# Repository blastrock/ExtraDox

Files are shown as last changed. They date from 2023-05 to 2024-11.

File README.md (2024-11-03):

# ExtraDox (v2)

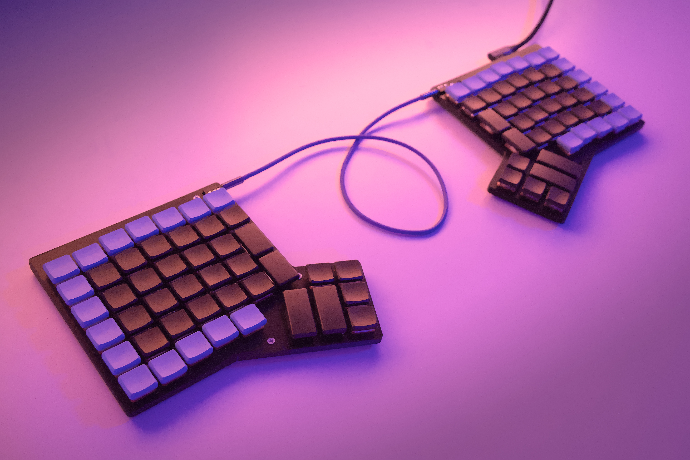
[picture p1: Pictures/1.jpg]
The ExtraDox


The ExtraDox is a split keyboard based off the ErgoDox. The main difference is
that it has an additional row of keys on the top. Also, it is a low-profile
keyboard designed for Choc v1 switches.

It features:

- An additional row of keys over the ErgoDox
- An USB-C port
- A single-board design (actually two boards), no extra controller board
- A TRRS connection between the two sides
- The 3 usual status LED
- The case is only 8mm thick, the keys are 18mm high from the desk

## What you need to build this keyboard

- The PCBs and their components (the MCU is soldered on the main board)
- The 3D-printed case
- 14x M2.5x8 screws and nuts
- 10x rubber pads to put under the keyboard to prevent slipping
- 90x Kailh Choc Hotswap sockets
- 90x Kailh Choc switches
- 82x 1u key caps
- 4x 1.5u key caps
- 4x 2u key caps
- 3x SMD status LED (see the Kicad project for details)
- 2x TRRS connector (see the Kicad project for details)
- 1x TRRS cable
- 1x USB-c cable

## About this keyboard

### PCB

The PCB is designed in Kicad. It is a SMD design and the project includes
component references from JLCPCB.

### Case

The case is designed to be 3D-printed. The case is screwed together with 7
M2.5x8 screws on each side, and their corresponding bolts.

### Firmware

[Here](https://github.com/blastrock/qmk_firmware/tree/extradox/keyboards/extradox) is a a fork of the QMK firmware with support for the ExtraDox.

## Known issues

Some capacitors are located right under an hotswap socket. It is still possible
to solder it, but the socket gets a little tilted.

## License



This work is licensed under a [Creative Commons Attribution-NonCommercial-ShareAlike 4.0 International License](http://creativecommons.org/licenses/by-nc-sa/4.0/).

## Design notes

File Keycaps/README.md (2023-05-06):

These keycaps are only used for renders, I never tried printing them.

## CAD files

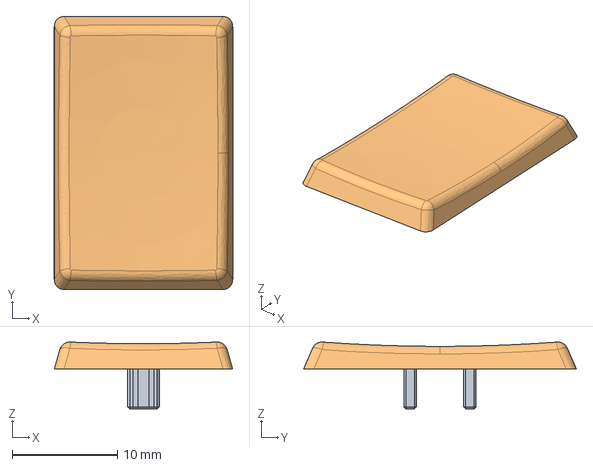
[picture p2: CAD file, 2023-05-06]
Keycaps/1.5u.step
17.0 x 26.0 x 6.38 mm

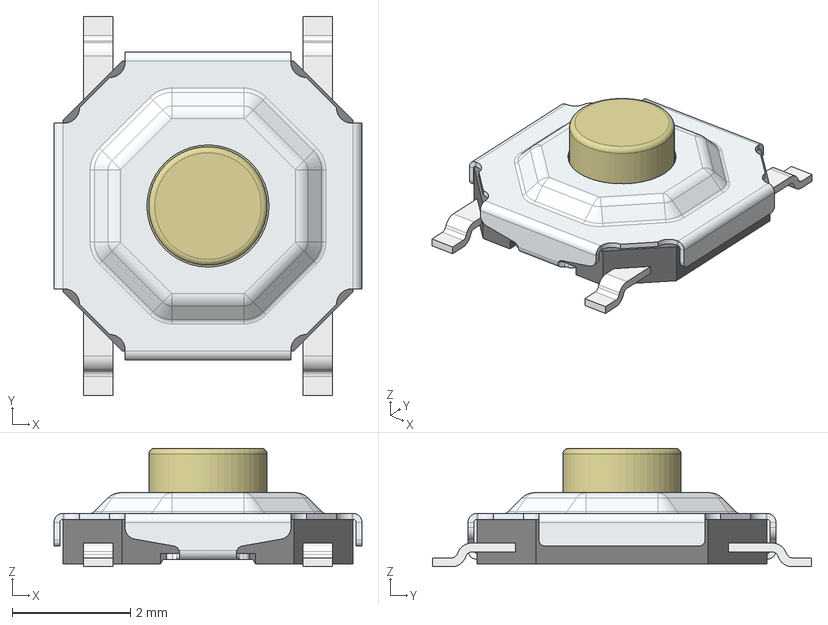
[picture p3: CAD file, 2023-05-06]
PCB/3dmodels/TS-1087S-020.stp
5.20 x 6.40 x 2.00 mm

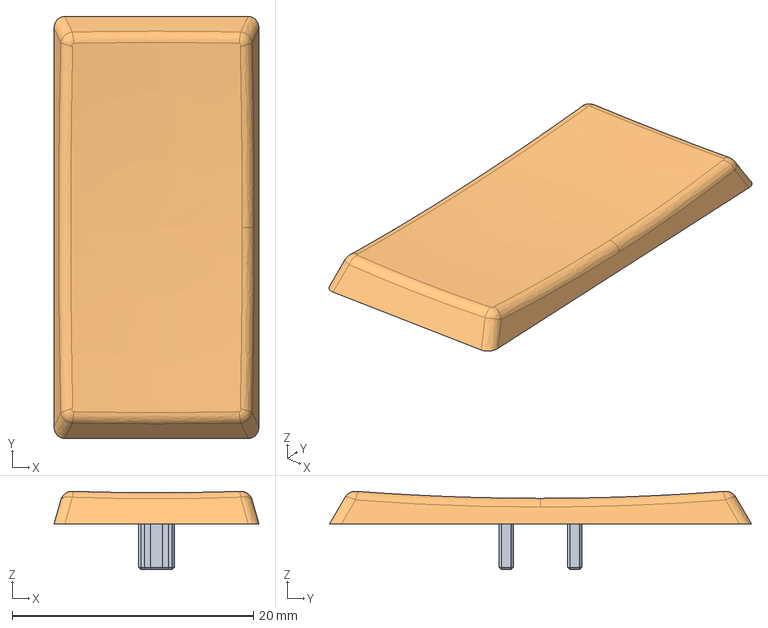
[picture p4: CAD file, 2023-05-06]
Keycaps/2u.step
17.0 x 35.0 x 6.50 mm

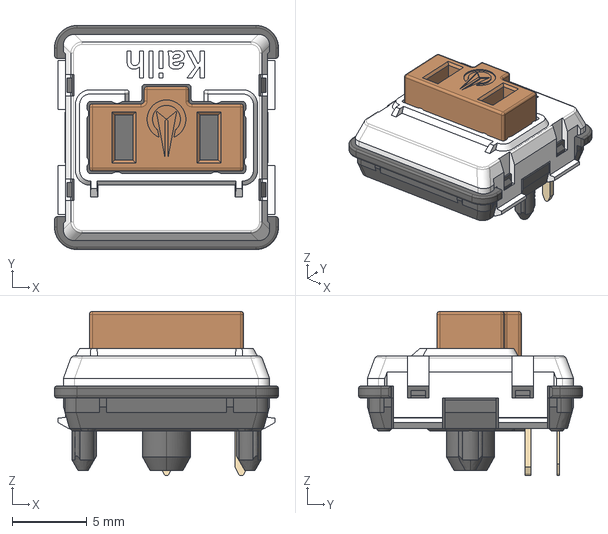
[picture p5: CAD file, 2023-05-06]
PCB/3dmodels/kailh_choc1.stp
15.0 x 15.0 x 11.0 mm

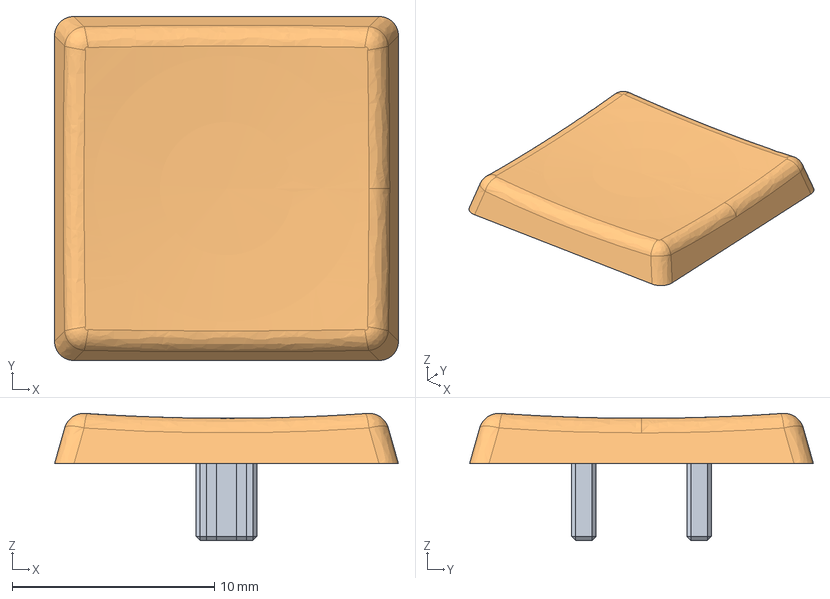
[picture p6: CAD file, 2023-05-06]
Keycaps/1u.step
17.0 x 17.0 x 6.29 mm

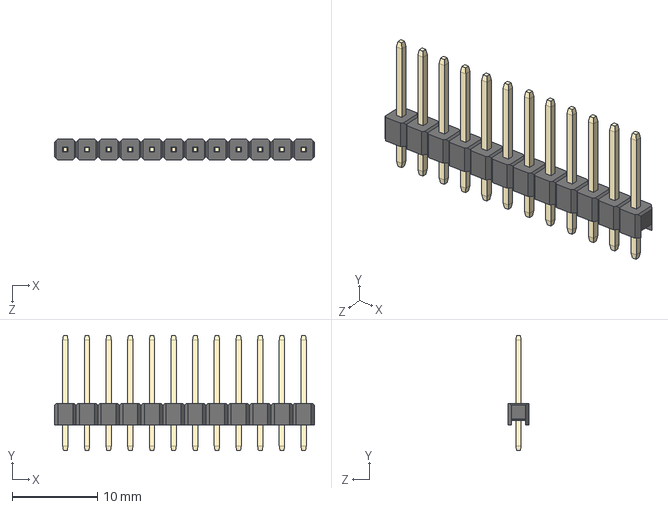
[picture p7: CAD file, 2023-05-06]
PCB/3dmodels/1x12 Male Pin Header.STEP
30.5 x 13.5 x 2.50 mm

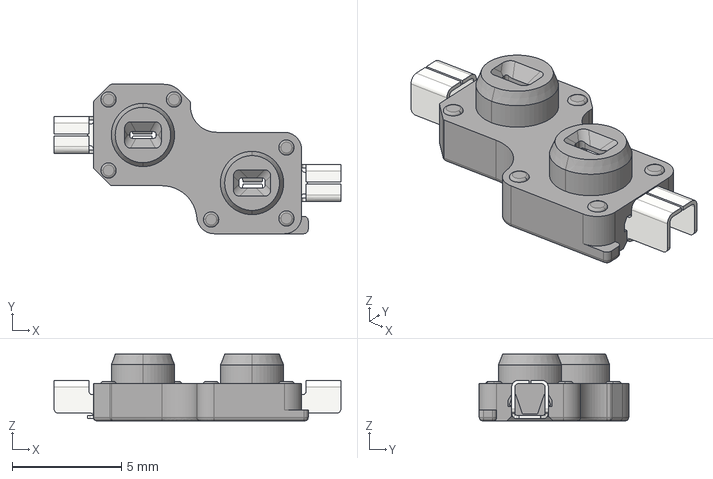
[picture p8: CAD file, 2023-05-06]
PCB/3dmodels/kailh_hotswap.stp
13.2 x 6.85 x 3.05 mm

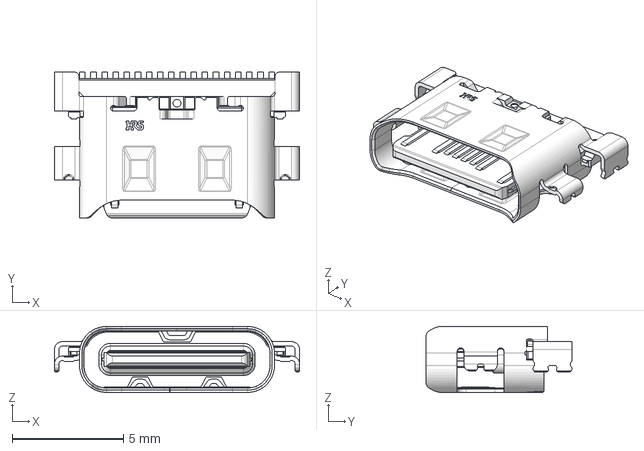
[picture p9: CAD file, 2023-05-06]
PCB/3dmodels/CX90M-16P.step
11.0 x 6.55 x 2.97 mm

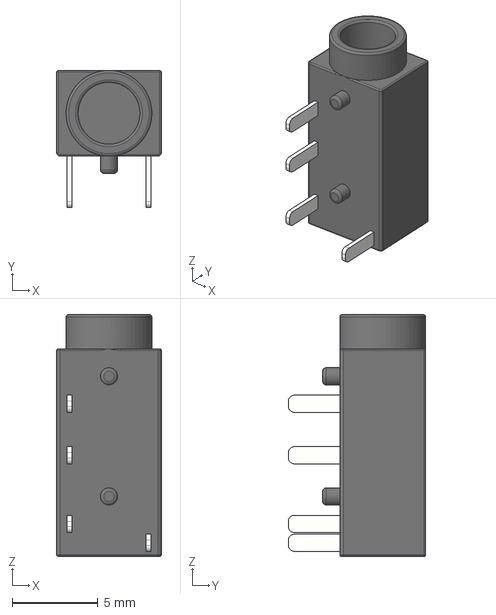
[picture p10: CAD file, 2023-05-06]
PCB/3dmodels/TRRS-PJ-320A.step
6.10 x 8.00 x 14.1 mm

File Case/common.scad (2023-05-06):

use <polyround.scad>
use <BOSL2/std.scad>
include <positions.scad>

boardThickness = 1.60;
caseRadius = 3;
bottomLayerThickness = 2;
boardHeight = bottomLayerThickness + 2;
topLayerThickness = 1.30;
topLayerOverBoard = boardThickness + 2.2-topLayerThickness;
topLayerHeight = topLayerOverBoard + boardHeight;
layerIntersectBottom = bottomLayerThickness + (topLayerHeight - bottomLayerThickness) / 2 - 0.5;
layerIntersectTop = bottomLayerThickness + (topLayerHeight - bottomLayerThickness) / 2 + 0.5;
screwHoleRadius = 3.2/2;
screwGuideBaseLargeRadius = 8/2;
screwGuideBaseRadius = 7/2;
screwGuideTopRadius = 5/2;
nutShortDiag = 5.4;
nutLongDiag = 2/sqrt(3) * nutShortDiag;

$fs = 0.5;

boardPoints = [
    [58, 64.5],
    [58, -62],
    [-11, -62],
    [-93, -100],
    [-118, -46],
    [-77, -27],
    [-77, 64.5],
];
outerShell = offset(boardPoints, delta=2, closed=true);
midShellIn = offset(boardPoints, delta=0.90, closed=true);
midShellOut = offset(boardPoints, delta=1.10, closed=true);

module base() {
  difference() {
    polyRoundExtrude([ for (p = outerShell) [ p.x, p.y, caseRadius ] ], layerIntersectTop, r1=0, r2=caseRadius);

    translate([0, 0, bottomLayerThickness])
      polyRoundExtrude([ for (p = boardPoints) [ p.x, p.y, caseRadius ] ], 10);
    translate([0, 0, layerIntersectBottom])
      difference() {
        translate([-150, -150, 0]) cube([300, 300, 10]);
        translate([0, 0, -5])
          polyRoundExtrude([ for (p = midShellOut) [ p.x, p.y, caseRadius ] ], 10, r1=0, r2=0);
      }
  }
}

module screwGuide() {
  color("green") cylinder(boardHeight, r1=screwGuideBaseLargeRadius, r2=screwGuideBaseRadius);
  //cylinder(topLayerHeight, r=screwGuideTopRadius);
}

module screwTopGuide() {
  cylinder(topLayerOverBoard-boardThickness+0.1, r=screwGuideTopRadius);
}

module screwCountersink() {
  h = 5;
  translate([0, 0, topLayerHeight-1])
    cylinder(h, r1=0, r2=h);
}

module screwHole() {
  translate([0, 0, -10])
    cylinder(r=screwHoleRadius, h=20);
}

module nutHole() {
  translate([0, 0, -1])
    cylinder(1+3, r=nutLongDiag/2, $fn=6);
}

module switchHole() {
  linear_extrude(100)
    square([14.3, 14], center=true);
}

module forHoles(holePositions) {
  for ( h = holePositions )
    translate([h.x, h.y])
      children();
}

module longHole(radius, width) {
  union() {
    translate([-width/2, 0])
    circle(radius);
    translate([+width/2, 0])
    circle(radius);
    square([width, radius*2], center=true);
  }
}

module usbcHole() {
  union() {
    linear_extrude(100)
      longHole(2, 6);
    translate([0, 0, 6])
      linear_extrude(100)
        longHole(3, 10);
  }
}

module jackHole() {
  union() {
    // linear_extrude(100)
    //   circle(d=6);
    translate([0, 0, -3])
      //cube([6, 6.5, 13], center=true);
      cube([10, 6.5, 20], center=true);
  }
}

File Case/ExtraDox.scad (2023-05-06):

use <rightBottom.scad>
use <rightTop.scad>
use <leftBottom.scad>
use <leftTop.scad>
include <common.scad>

part_rightBottomCase();
part_rightTopCase();

%translate([0, 0, boardHeight])
  import("ExtraDox-Right.stl");

translate([-250, 0, 0]) {
  part_leftBottomCase();
  part_leftTopCase();

  %translate([0, 0, boardHeight])
    import("ExtraDox-Left.stl");
}

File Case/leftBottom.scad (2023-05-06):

include <common.scad>

module part_leftBottomCase() {
  difference() {
    union() {
      mirror([1, 0, 0])
        base();
      forHoles(leftHolePositions)
        screwGuide();
    }
    forHoles(leftHolePositions) {
      screwHole();
      nutHole();
    }
  }
}

part_leftBottomCase();

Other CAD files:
Case/ExtraDox-Right.step
Case/ExtraDox-Left.step
PCB/3dmodels/choc2u.step
PCB/3dmodels/choc1_5u.step
PCB/3dmodels/Kailh Choc FunkMonk 1u.step
Case/leftTop.scad
Case/polyround.scad
Case/positions.scad
Case/rightBottom.scad
Case/rightTop.scad
Keycaps/1u.FCStd

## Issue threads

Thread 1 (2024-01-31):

Boards

Yenots83, 2024-01-31:
Hi!

Was wondering if you still had any boards for sale?

Think this is the only way to get in touch :)

blastrock, 2024-02-01:
Hello!

Unfortunately, I shipped my last boards a couple weeks ago, I don't have any more to sell.

Closed 2024-02-01.

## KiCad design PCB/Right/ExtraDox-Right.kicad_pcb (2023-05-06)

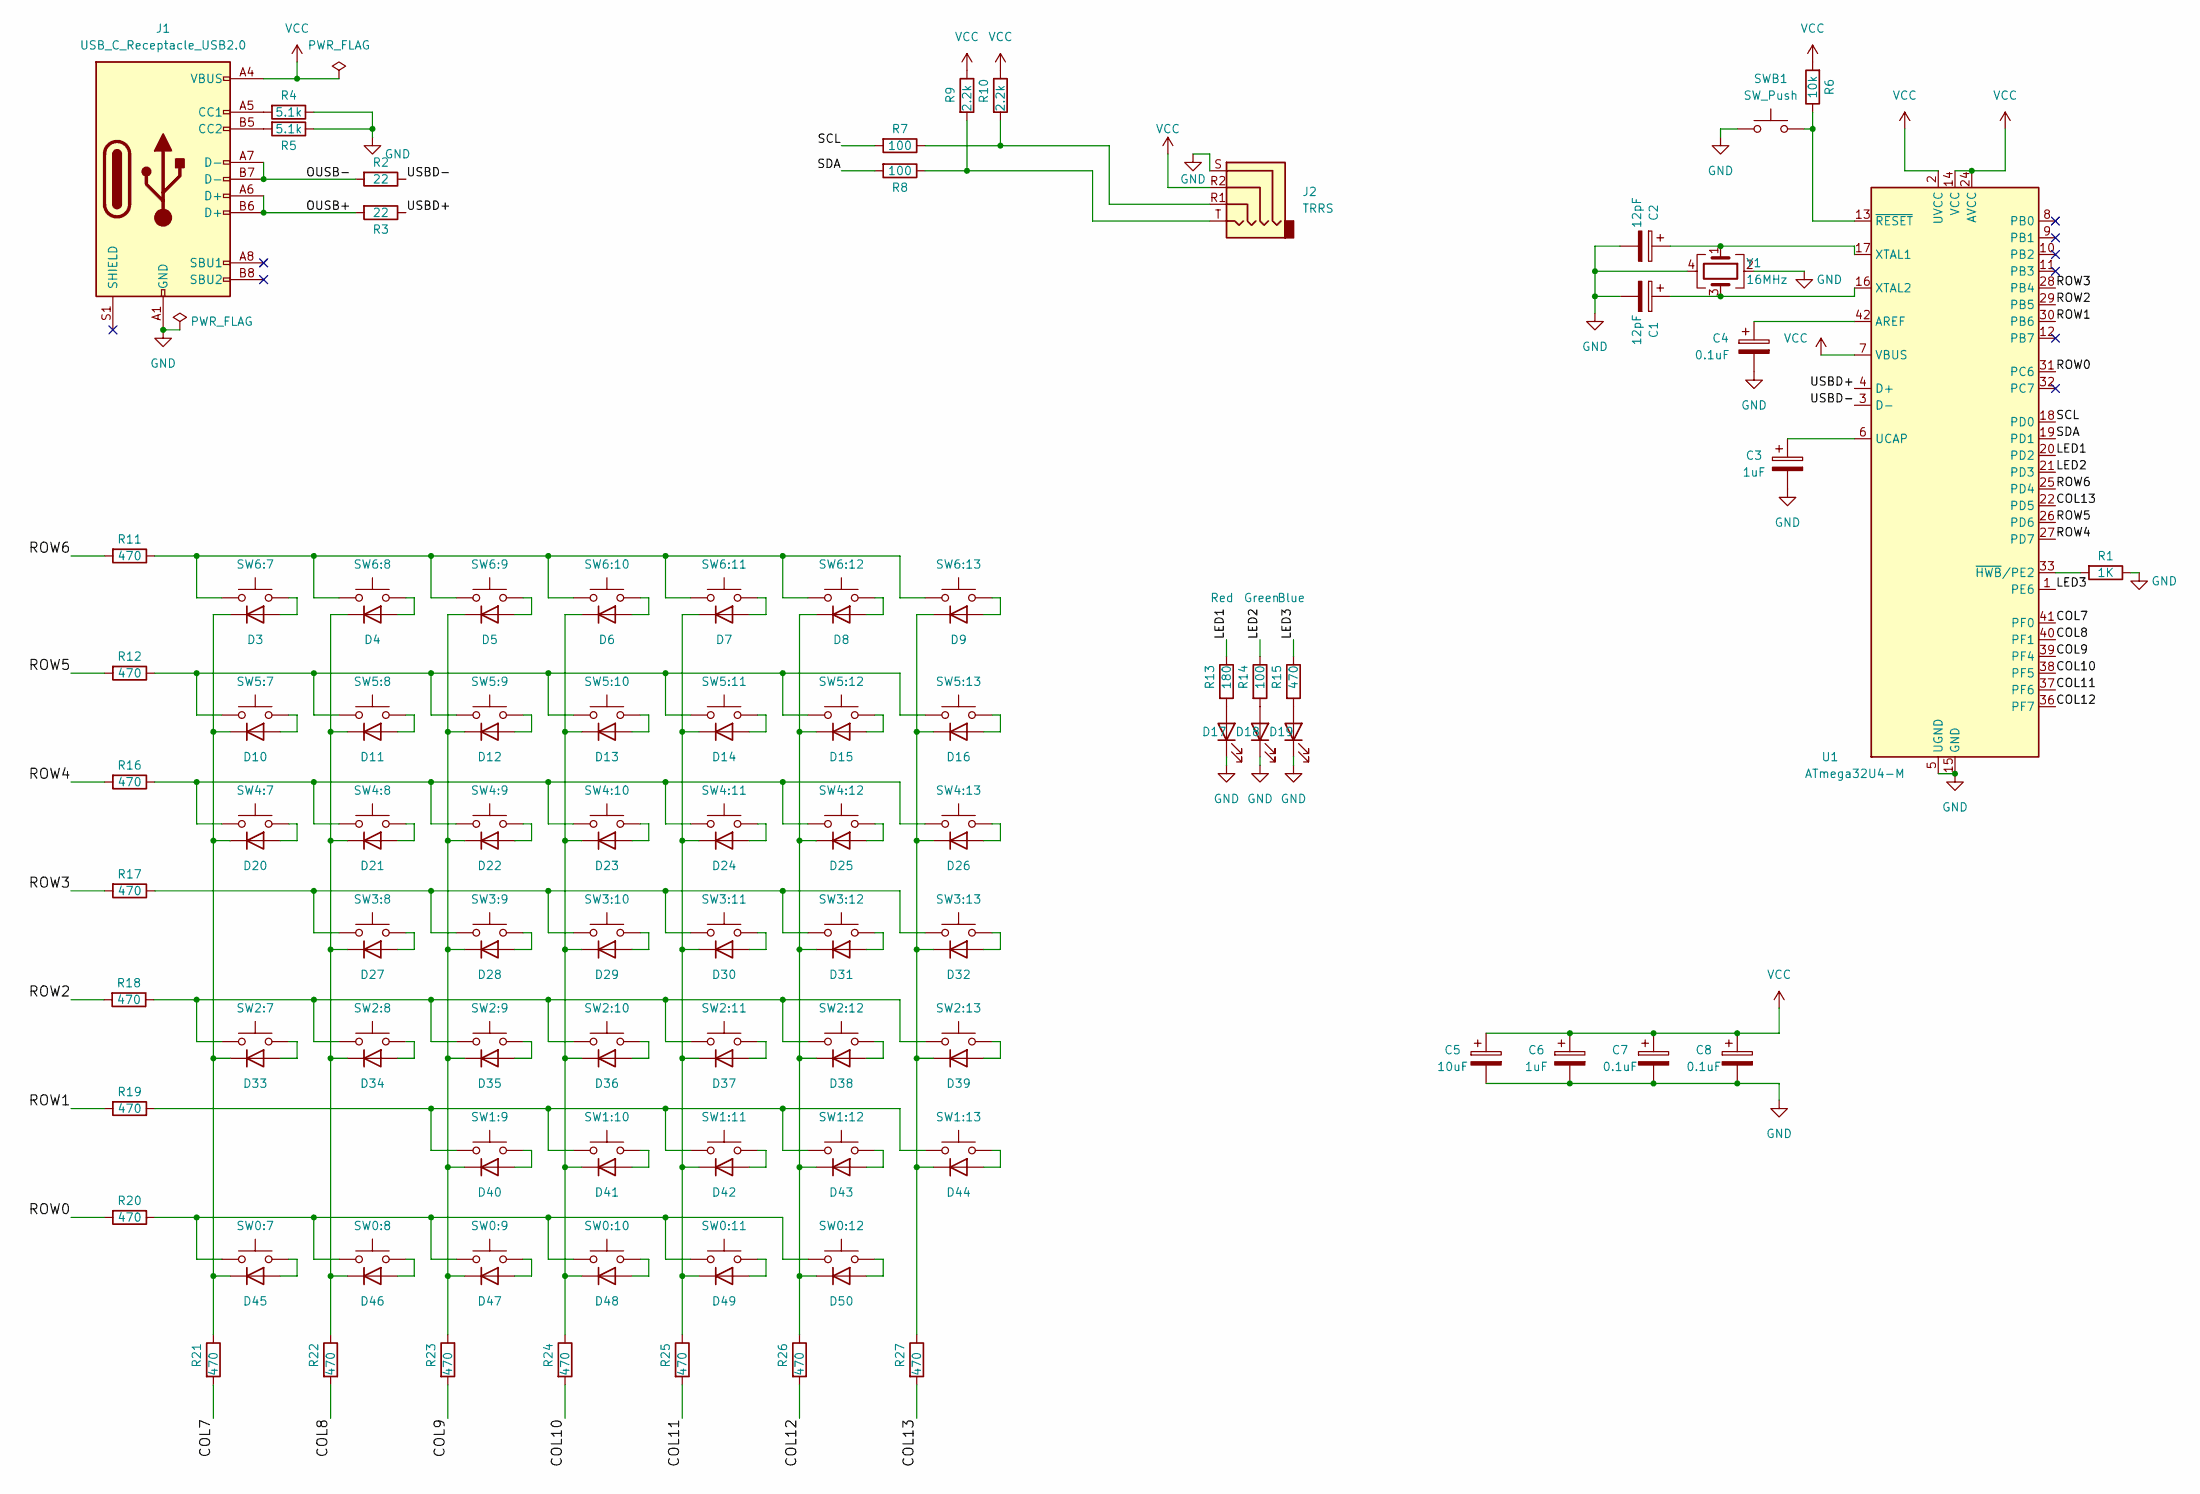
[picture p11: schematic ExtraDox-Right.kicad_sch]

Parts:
C1, C2: 12pF; C_0402_1005Metric; LCSC C1547
C3, C6: 1uF; C_0402_1005Metric; LCSC C52923
C4, C7, C8: 0.1uF; C_0402_1005Metric; LCSC C307331
C5: 10uF; C_0402_1005Metric; LCSC C15525
D3, D4, D5, D6, D7, D8, D9, D10, D11, D12, D13, D14, D15, D16, D20, D21, D22, D23, D24, D25, D26, D27, D28, D29, D30, D31, D32, D33, D34, D35, D36, D37, D38, D39, D40, D41, D42, D43, D44, D45, D46, D47, D48, D49, D50: D; D_SOD-123F; LCSC C64898
D17: Red; D_0603_1608Metric; LCSC C2286
D18: Green; D_0603_1608Metric; LCSC C72043
D19: Blue; D_0603_1608Metric; LCSC C72041
J1: USB_C_Receptacle_USB2.0; HRS_CX90M-16P; LCSC C2889324
J2: TRRS; TRRS-PJ-320A
R1: 1K; R_0402_1005Metric; LCSC C11702
R2, R3: 22; R_0402_1005Metric; LCSC C25092
R4, R5: 5.1k; R_0402_1005Metric; LCSC C25905
R6: 10k; R_0402_1005Metric; LCSC C25744
R7, R8, R14: 100; R_0402_1005Metric; LCSC C25076
R9, R10: 2.2k; R_0402_1005Metric; LCSC C25879
R11, R12, R15, R16, R17, R18, R19, R20, R21, R22, R23, R24, R25, R26, R27: 470; R_0402_1005Metric; LCSC C25117
R13: 180; R_0402_1005Metric; LCSC C25082
SW0:7, SW0:8, SW0:9, SW0:12, SW1:9, SW1:10, SW1:11, SW1:12, SW1:13, SW2:8, SW2:9, SW2:10, SW2:11, SW2:12, SW2:13, SW3:8, SW3:9, SW3:10, SW3:11, SW3:12, SW3:13, SW4:8, SW4:9, SW4:10, SW4:11, SW4:12, SW4:13, SW5:7, SW5:8, SW5:9, SW5:10, SW5:11, SW5:12, SW5:13, SW6:7, SW6:8, SW6:9, SW6:10, SW6:11, SW6:12, SW6:13: SW_Push; KailhHotswapChoc1
SW0:10, SW0:11: SW_Push; KailhHotswapChoc2
SW2:7, SW4:7: SW_Push; KailhHotswapChoc15
SWB1: SW_Push; TS-1087S; LCSC C455263
U1: ATmega32U4-M; QFN-44-1EP_7x7mm_P0.5mm_EP5.2x5.2mm_ThermalVias_JLCPCB; LCSC C112161
Y1: 16MHz; Crystal_SMD_3225-4Pin_3.2x2.5mm; LCSC C13738

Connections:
/COL7: R21.2, U1.41 (PF0)
/COL8: R22.2, U1.40 (PF1)
/COL9: R23.2, U1.39 (PF4)
/COL10: R24.2, U1.38 (PF5)
/COL11: R25.2, U1.37 (PF6)
/COL12: R26.2, U1.36 (PF7)
/COL13: R27.2, U1.22 (PD5)
/LED1: R13.1, U1.20 (PD2)
/LED2: R14.1, U1.21 (PD3)
/LED3: R15.1, U1.1 (PE6)
/OUSB+: J1.A6 (D+), J1.B6 (D+), R3.2
/OUSB-: J1.A7 (D-), J1.B7 (D-), R2.2
/ROW0: R20.2, U1.31 (PC6)
/ROW1: R19.2, U1.30 (PB6)
/ROW2: R18.2, U1.29 (PB5)
/ROW3: R17.2, U1.28 (PB4)
/ROW4: R16.2, U1.27 (PD7)
/ROW5: R12.2, U1.26 (PD6)
/ROW6: R11.2, U1.25 (PD4)
/SCL: R7.2, U1.18 (PD0)
/SDA: R8.2, U1.19 (PD1)
/USBD+: R3.1, U1.4 (D+)
/USBD-: R2.1, U1.3 (D-)
GND: C1.2, C2.2, C3.2, C4.2, C5.2, C6.2, C7.2, C8.2, D17.1 (K), D18.1 (K), D19.1 (K), J1.A1 (GND), J1.A12 (GND), J1.B1 (GND), J1.B12 (GND), J2.S, R1.1, R4.1, R5.1, SWB1.1, U1.5 (UGND), U1.15 (GND), U1.23 (GND), U1.35 (GND), U1.43 (GND), U1.45 (GND), Y1.2, Y1.4
unnamed: C1.1, U1.16 (XTAL2), Y1.3
unnamed: C2.1, U1.17 (XTAL1), Y1.1
unnamed: C3.1, U1.6 (UCAP)
unnamed: C4.1, U1.42 (AREF)
unnamed: D3.2 (A), SW6:7.2
unnamed: D4.2 (A), SW6:8.2
unnamed: D5.2 (A), SW6:9.2
unnamed: D6.2 (A), SW6:10.2
unnamed: D7.2 (A), SW6:11.2
unnamed: D8.2 (A), SW6:12.2
unnamed: D9.2 (A), SW6:13.2
unnamed: D3.1 (K), D10.1 (K), D20.1 (K), D33.1 (K), D45.1 (K), R21.1
unnamed: D10.2 (A), SW5:7.2
unnamed: D4.1 (K), D11.1 (K), D21.1 (K), D27.1 (K), D34.1 (K), D46.1 (K), R22.1
unnamed: D11.2 (A), SW5:8.2
unnamed: D5.1 (K), D12.1 (K), D22.1 (K), D28.1 (K), D35.1 (K), D40.1 (K), D47.1 (K), R23.1
unnamed: D12.2 (A), SW5:9.2
unnamed: D6.1 (K), D13.1 (K), D23.1 (K), D29.1 (K), D36.1 (K), D41.1 (K), D48.1 (K), R24.1
unnamed: D13.2 (A), SW5:10.2
unnamed: D7.1 (K), D14.1 (K), D24.1 (K), D30.1 (K), D37.1 (K), D42.1 (K), D49.1 (K), R25.1
unnamed: D14.2 (A), SW5:11.2
unnamed: D8.1 (K), D15.1 (K), D25.1 (K), D31.1 (K), D38.1 (K), D43.1 (K), D50.1 (K), R26.1
unnamed: D15.2 (A), SW5:12.2
unnamed: D9.1 (K), D16.1 (K), D26.1 (K), D32.1 (K), D39.1 (K), D44.1 (K), R27.1
unnamed: D16.2 (A), SW5:13.2
unnamed: D17.2 (A), R13.2
unnamed: D18.2 (A), R14.2
unnamed: D19.2 (A), R15.2
unnamed: D20.2 (A), SW4:7.2
unnamed: D21.2 (A), SW4:8.2
unnamed: D22.2 (A), SW4:9.2
unnamed: D23.2 (A), SW4:10.2
unnamed: D24.2 (A), SW4:11.2
unnamed: D25.2 (A), SW4:12.2
unnamed: D26.2 (A), SW4:13.2
unnamed: D27.2 (A), SW3:8.2
unnamed: D28.2 (A), SW3:9.2
unnamed: D29.2 (A), SW3:10.2
unnamed: D30.2 (A), SW3:11.2
unnamed: D31.2 (A), SW3:12.2
unnamed: D32.2 (A), SW3:13.2
unnamed: D33.2 (A), SW2:7.2
unnamed: D34.2 (A), SW2:8.2
unnamed: D35.2 (A), SW2:9.2
unnamed: D36.2 (A), SW2:10.2
unnamed: D37.2 (A), SW2:11.2
unnamed: D38.2 (A), SW2:12.2
unnamed: D39.2 (A), SW2:13.2
unnamed: D40.2 (A), SW1:9.2
unnamed: D41.2 (A), SW1:10.2
unnamed: D42.2 (A), SW1:11.2
unnamed: D43.2 (A), SW1:12.2
unnamed: D44.2 (A), SW1:13.2
unnamed: D45.2 (A), SW0:7.2
unnamed: D46.2 (A), SW0:8.2
unnamed: D47.2 (A), SW0:9.2
unnamed: D48.2 (A), SW0:10.2
unnamed: D49.2 (A), SW0:11.2
unnamed: D50.2 (A), SW0:12.2
unnamed: J1.A5 (CC1), R4.2
unnamed: J1.B5 (CC2), R5.2
unnamed: J2.R1, R7.1, R10.2
unnamed: J2.T, R8.1, R9.2
unnamed: R1.2, U1.33 (~HWB/PE2)
unnamed: R6.1, SWB1.2, U1.13 (~RESET)
unnamed: R11.1, SW6:7.1, SW6:8.1, SW6:9.1, SW6:10.1, SW6:11.1, SW6:12.1, SW6:13.1
unnamed: R12.1, SW5:7.1, SW5:8.1, SW5:9.1, SW5:10.1, SW5:11.1, SW5:12.1, SW5:13.1
unnamed: R16.1, SW4:7.1, SW4:8.1, SW4:9.1, SW4:10.1, SW4:11.1, SW4:12.1, SW4:13.1
unnamed: R17.1, SW3:8.1, SW3:9.1, SW3:10.1, SW3:11.1, SW3:12.1, SW3:13.1
unnamed: R18.1, SW2:7.1, SW2:8.1, SW2:9.1, SW2:10.1, SW2:11.1, SW2:12.1, SW2:13.1
unnamed: R19.1, SW1:9.1, SW1:10.1, SW1:11.1, SW1:12.1, SW1:13.1
unnamed: R20.1, SW0:7.1, SW0:8.1, SW0:9.1, SW0:10.1, SW0:11.1, SW0:12.1
VCC: C5.1, C6.1, C7.1, C8.1, J1.A4 (VBUS), J1.A9 (VBUS), J1.B4 (VBUS), J1.B9 (VBUS), J2.R2, R6.2, R9.1, R10.1, U1.2 (UVCC), U1.7 (VBUS), U1.14 (VCC), U1.24 (AVCC), U1.34 (VCC), U1.44 (AVCC)

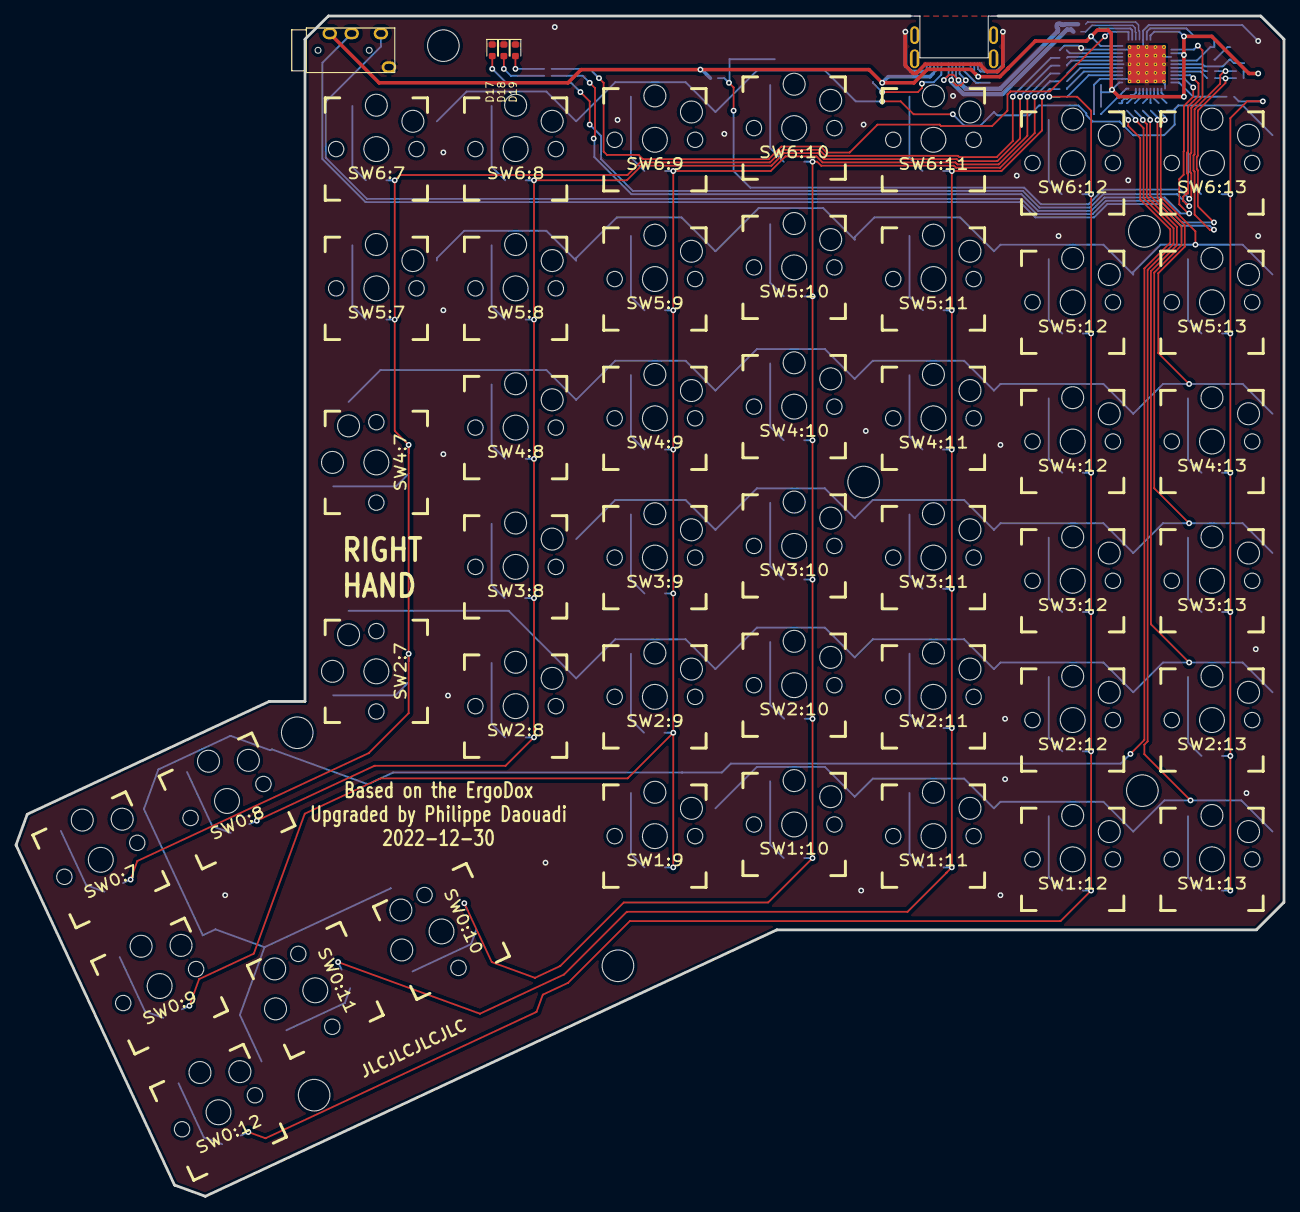
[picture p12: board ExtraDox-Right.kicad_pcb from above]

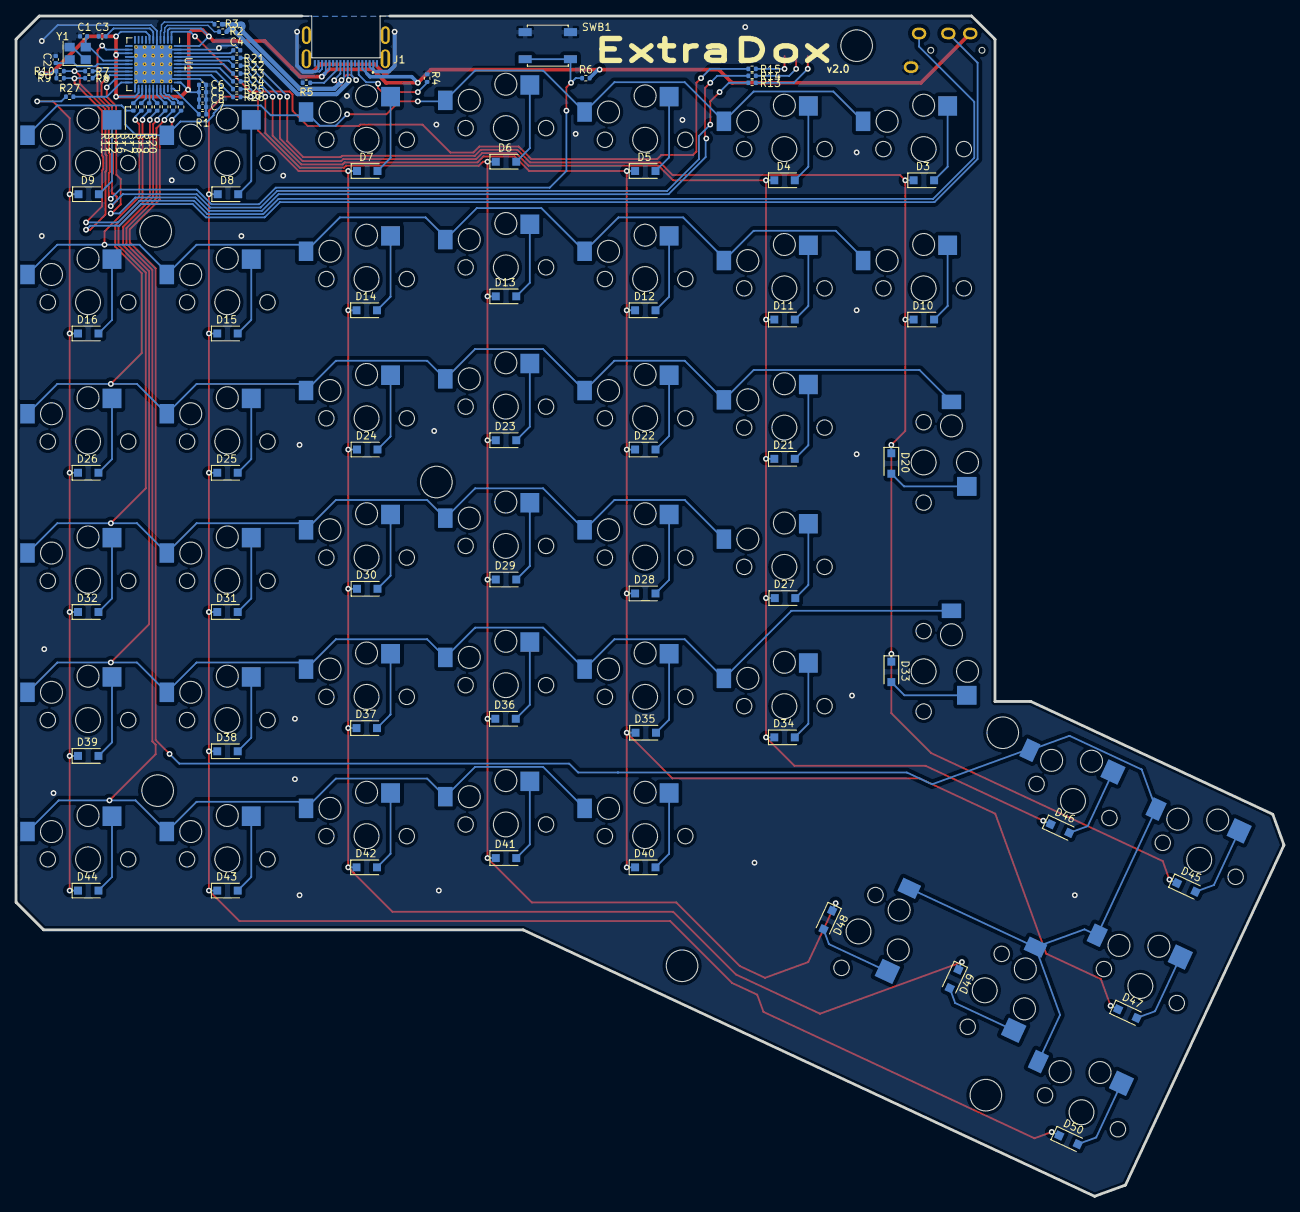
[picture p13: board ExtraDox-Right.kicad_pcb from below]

Board: 2 copper layers, 173.4 x 161.4 mm, 133 parts (84 on the bottom side), 97 nets.

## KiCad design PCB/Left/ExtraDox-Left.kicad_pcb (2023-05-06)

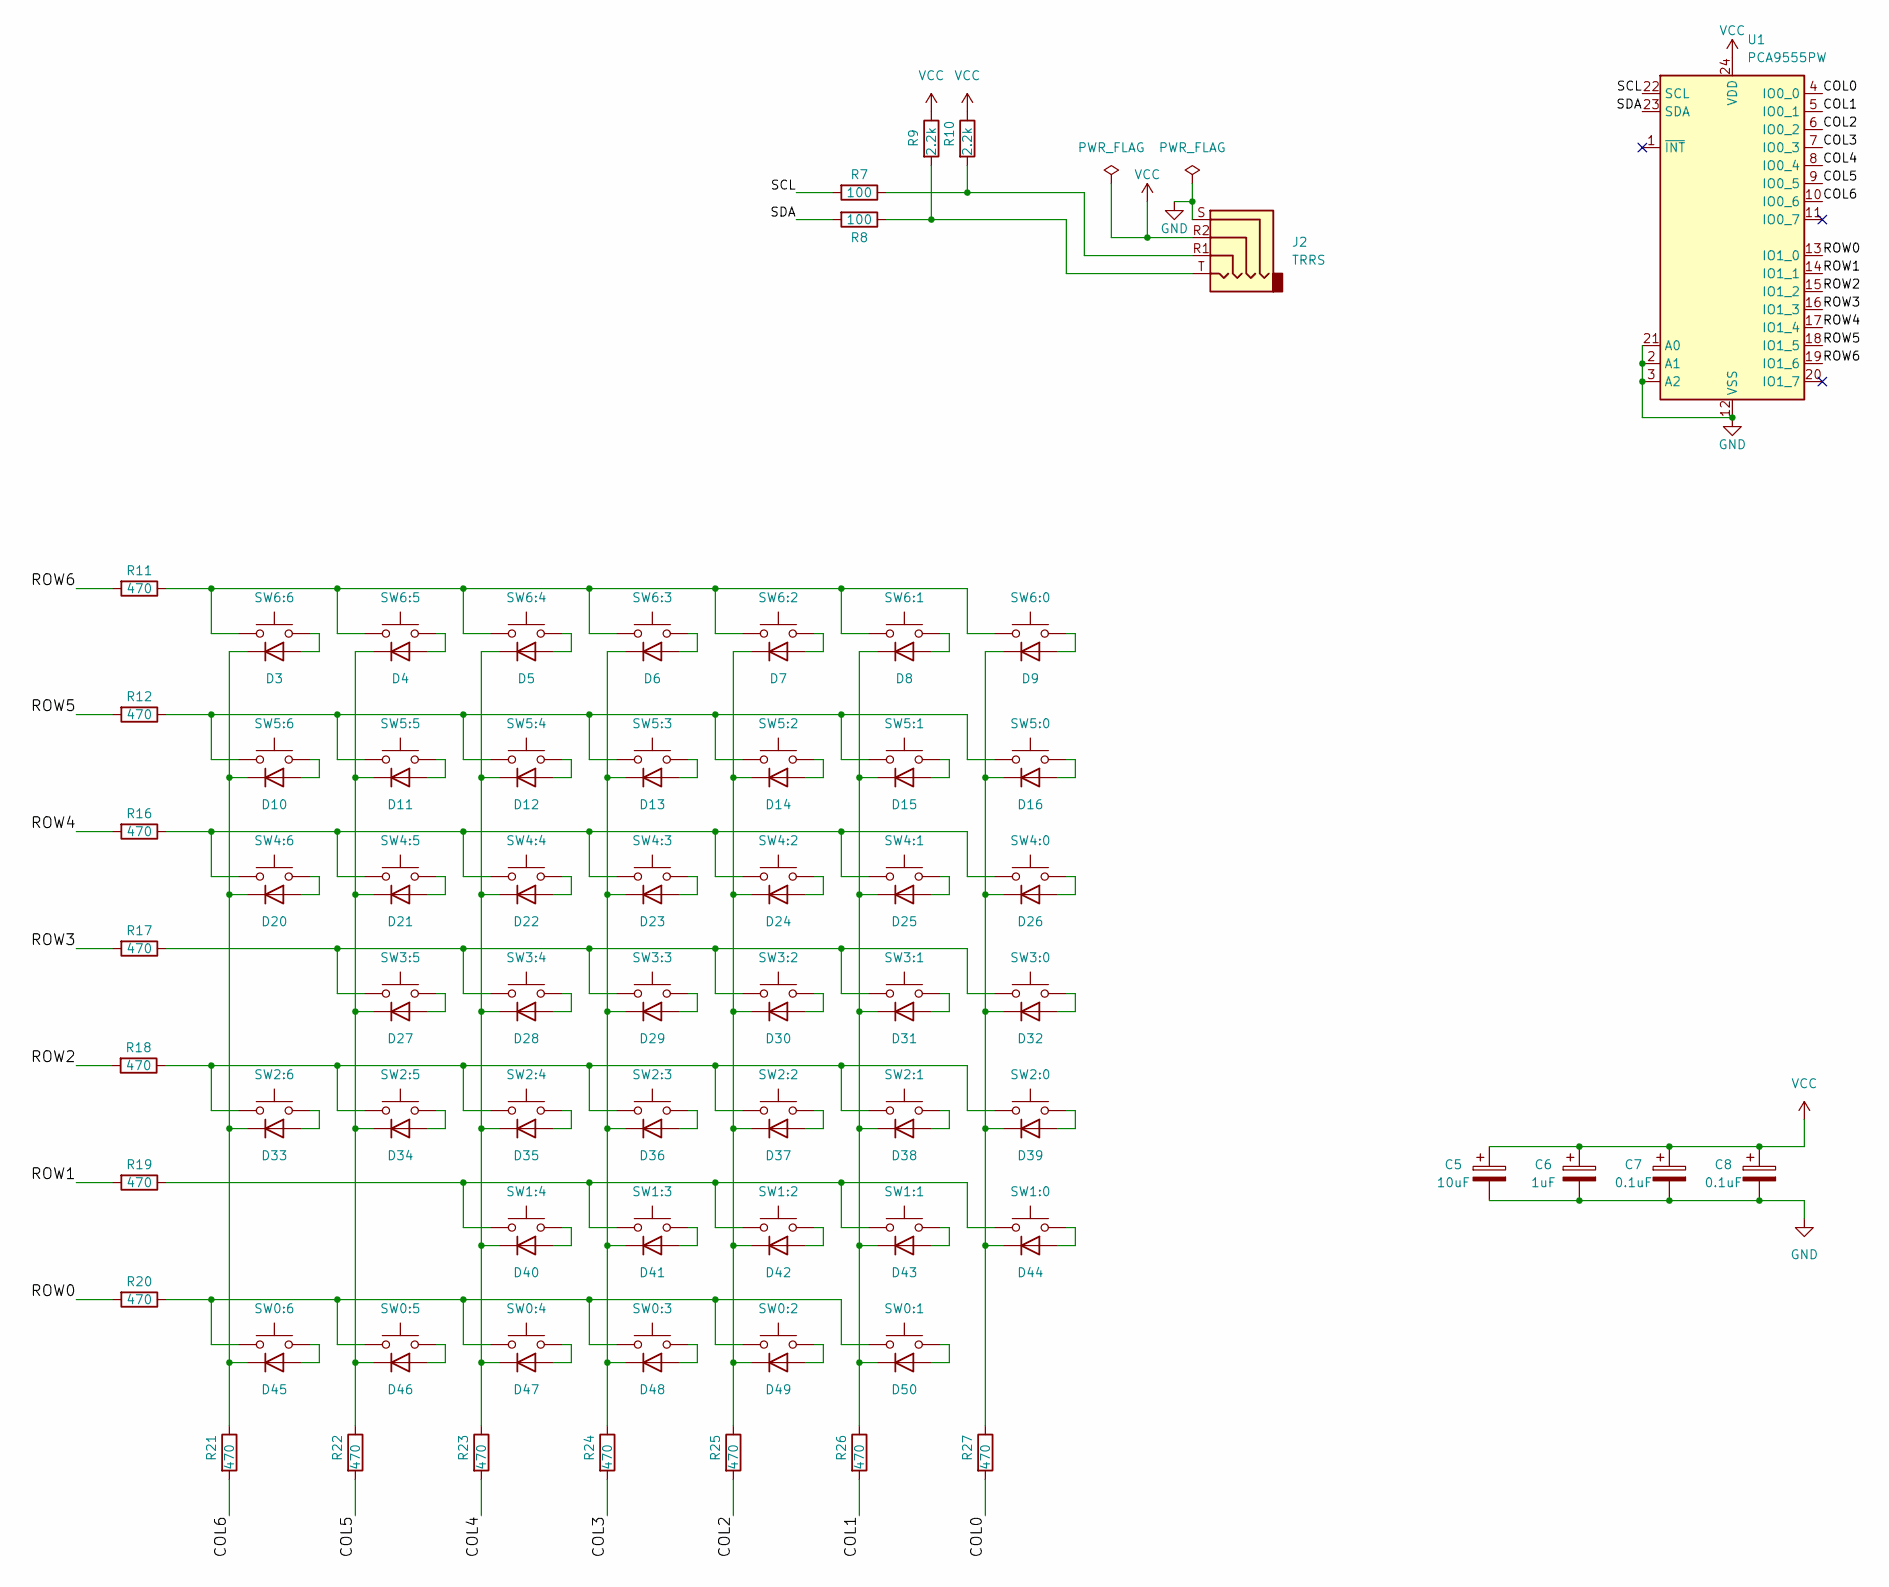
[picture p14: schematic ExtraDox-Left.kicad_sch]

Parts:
C5: 10uF; C_0402_1005Metric; LCSC C15525
C6: 1uF; C_0402_1005Metric; LCSC C52923
C7, C8: 0.1uF; C_0402_1005Metric; LCSC C307331
D3, D4, D5, D6, D7, D8, D9, D10, D11, D12, D13, D14, D15, D16, D20, D21, D22, D23, D24, D25, D26, D27, D28, D29, D30, D31, D32, D33, D34, D35, D36, D37, D38, D39, D40, D41, D42, D43, D44, D45, D46, D47, D48, D49, D50: D; D_SOD-123F; LCSC C64898
J2: TRRS; TRRS-PJ-320A
R7, R8: 100; R_0402_1005Metric; LCSC C25076
R9, R10: 2.2k; R_0402_1005Metric; LCSC C25879
R11, R12, R16, R17, R18, R19, R20, R21, R22, R23, R24, R25, R26, R27: 470; R_0402_1005Metric; LCSC C25117
SW0:1, SW0:4, SW0:5, SW0:6, SW1:0, SW1:1, SW1:2, SW1:3, SW1:4, SW2:0, SW2:1, SW2:2, SW2:3, SW2:4, SW2:5, SW3:0, SW3:1, SW3:2, SW3:3, SW3:4, SW3:5, SW4:0, SW4:1, SW4:2, SW4:3, SW4:4, SW4:5, SW5:0, SW5:1, SW5:2, SW5:3, SW5:4, SW5:5, SW5:6, SW6:0, SW6:1, SW6:2, SW6:3, SW6:4, SW6:5, SW6:6: SW_Push; KailhHotswapChoc1
SW0:2, SW0:3: SW_Push; KailhHotswapChoc2
SW2:6, SW4:6: SW_Push; KailhHotswapChoc15
U1: PCA9555PW; TSSOP-24_4.4x7.8mm_P0.65mm_JLCPCB; LCSC C128392

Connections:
/COL0: R27.2, U1.4 (IO0_0)
/COL1: R26.2, U1.5 (IO0_1)
/COL2: R25.2, U1.6 (IO0_2)
/COL3: R24.2, U1.7 (IO0_3)
/COL4: R23.2, U1.8 (IO0_4)
/COL5: R22.2, U1.9 (IO0_5)
/COL6: R21.2, U1.10 (IO0_6)
/ROW0: R20.2, U1.13 (IO1_0)
/ROW1: R19.2, U1.14 (IO1_1)
/ROW2: R18.2, U1.15 (IO1_2)
/ROW3: R17.2, U1.16 (IO1_3)
/ROW4: R16.2, U1.17 (IO1_4)
/ROW5: R12.2, U1.18 (IO1_5)
/ROW6: R11.2, U1.19 (IO1_6)
/SCL: R7.2, U1.22 (SCL)
/SDA: R8.2, U1.23 (SDA)
GND: C5.2, C6.2, C7.2, C8.2, J2.S, U1.2 (A1), U1.3 (A2), U1.12 (VSS), U1.21 (A0)
unnamed: D3.2 (A), SW6:6.2
unnamed: D4.2 (A), SW6:5.2
unnamed: D5.2 (A), SW6:4.2
unnamed: D6.2 (A), SW6:3.2
unnamed: D7.2 (A), SW6:2.2
unnamed: D8.2 (A), SW6:1.2
unnamed: D9.2 (A), SW6:0.2
unnamed: D3.1 (K), D10.1 (K), D20.1 (K), D33.1 (K), D45.1 (K), R21.1
unnamed: D10.2 (A), SW5:6.2
unnamed: D4.1 (K), D11.1 (K), D21.1 (K), D27.1 (K), D34.1 (K), D46.1 (K), R22.1
unnamed: D11.2 (A), SW5:5.2
unnamed: D5.1 (K), D12.1 (K), D22.1 (K), D28.1 (K), D35.1 (K), D40.1 (K), D47.1 (K), R23.1
unnamed: D12.2 (A), SW5:4.2
unnamed: D6.1 (K), D13.1 (K), D23.1 (K), D29.1 (K), D36.1 (K), D41.1 (K), D48.1 (K), R24.1
unnamed: D13.2 (A), SW5:3.2
unnamed: D7.1 (K), D14.1 (K), D24.1 (K), D30.1 (K), D37.1 (K), D42.1 (K), D49.1 (K), R25.1
unnamed: D14.2 (A), SW5:2.2
unnamed: D8.1 (K), D15.1 (K), D25.1 (K), D31.1 (K), D38.1 (K), D43.1 (K), D50.1 (K), R26.1
unnamed: D15.2 (A), SW5:1.2
unnamed: D9.1 (K), D16.1 (K), D26.1 (K), D32.1 (K), D39.1 (K), D44.1 (K), R27.1
unnamed: D16.2 (A), SW5:0.2
unnamed: D20.2 (A), SW4:6.2
unnamed: D21.2 (A), SW4:5.2
unnamed: D22.2 (A), SW4:4.2
unnamed: D23.2 (A), SW4:3.2
unnamed: D24.2 (A), SW4:2.2
unnamed: D25.2 (A), SW4:1.2
unnamed: D26.2 (A), SW4:0.2
unnamed: D27.2 (A), SW3:5.2
unnamed: D28.2 (A), SW3:4.2
unnamed: D29.2 (A), SW3:3.2
unnamed: D30.2 (A), SW3:2.2
unnamed: D31.2 (A), SW3:1.2
unnamed: D32.2 (A), SW3:0.2
unnamed: D33.2 (A), SW2:6.2
unnamed: D34.2 (A), SW2:5.2
unnamed: D35.2 (A), SW2:4.2
unnamed: D36.2 (A), SW2:3.2
unnamed: D37.2 (A), SW2:2.2
unnamed: D38.2 (A), SW2:1.2
unnamed: D39.2 (A), SW2:0.2
unnamed: D40.2 (A), SW1:4.2
unnamed: D41.2 (A), SW1:3.2
unnamed: D42.2 (A), SW1:2.2
unnamed: D43.2 (A), SW1:1.2
unnamed: D44.2 (A), SW1:0.2
unnamed: D45.2 (A), SW0:6.2
unnamed: D46.2 (A), SW0:5.2
unnamed: D47.2 (A), SW0:4.2
unnamed: D48.2 (A), SW0:3.2
unnamed: D49.2 (A), SW0:2.2
unnamed: D50.2 (A), SW0:1.2
unnamed: J2.R1, R7.1, R10.2
unnamed: J2.T, R8.1, R9.2
unnamed: R11.1, SW6:0.1, SW6:1.1, SW6:2.1, SW6:3.1, SW6:4.1, SW6:5.1, SW6:6.1
unnamed: R12.1, SW5:0.1, SW5:1.1, SW5:2.1, SW5:3.1, SW5:4.1, SW5:5.1, SW5:6.1
unnamed: R16.1, SW4:0.1, SW4:1.1, SW4:2.1, SW4:3.1, SW4:4.1, SW4:5.1, SW4:6.1
unnamed: R17.1, SW3:0.1, SW3:1.1, SW3:2.1, SW3:3.1, SW3:4.1, SW3:5.1
unnamed: R18.1, SW2:0.1, SW2:1.1, SW2:2.1, SW2:3.1, SW2:4.1, SW2:5.1, SW2:6.1
unnamed: R19.1, SW1:0.1, SW1:1.1, SW1:2.1, SW1:3.1, SW1:4.1
unnamed: R20.1, SW0:1.1, SW0:2.1, SW0:3.1, SW0:4.1, SW0:5.1, SW0:6.1
VCC: C5.1, C6.1, C7.1, C8.1, J2.R2, R9.1, R10.1, U1.24 (VDD)

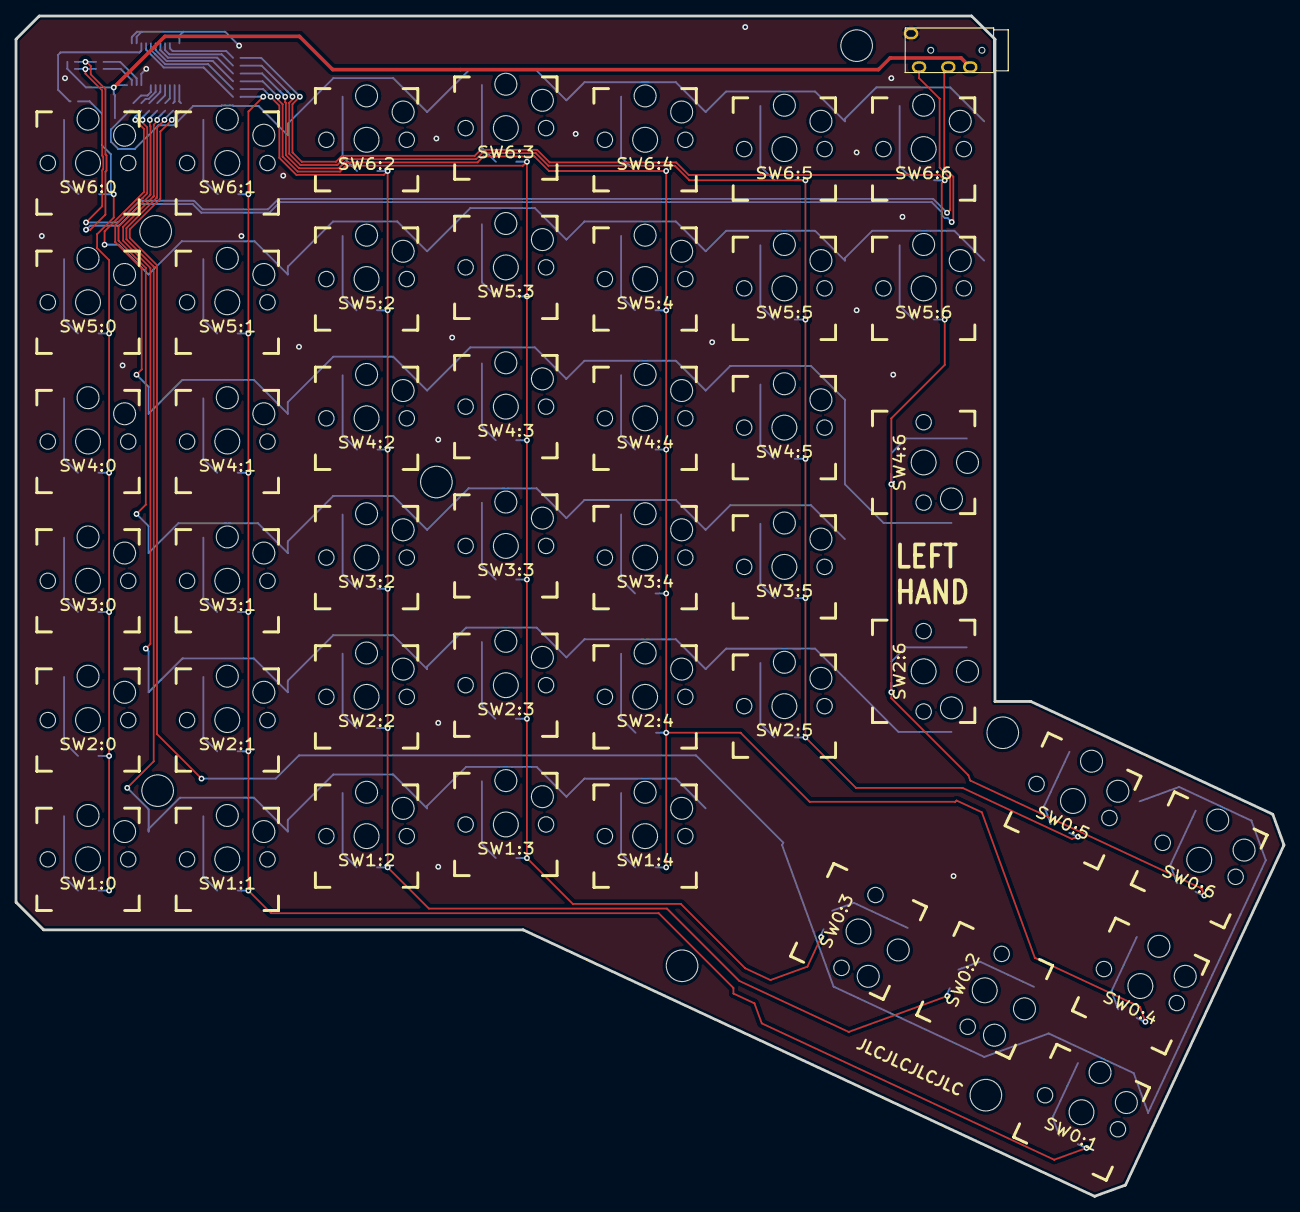
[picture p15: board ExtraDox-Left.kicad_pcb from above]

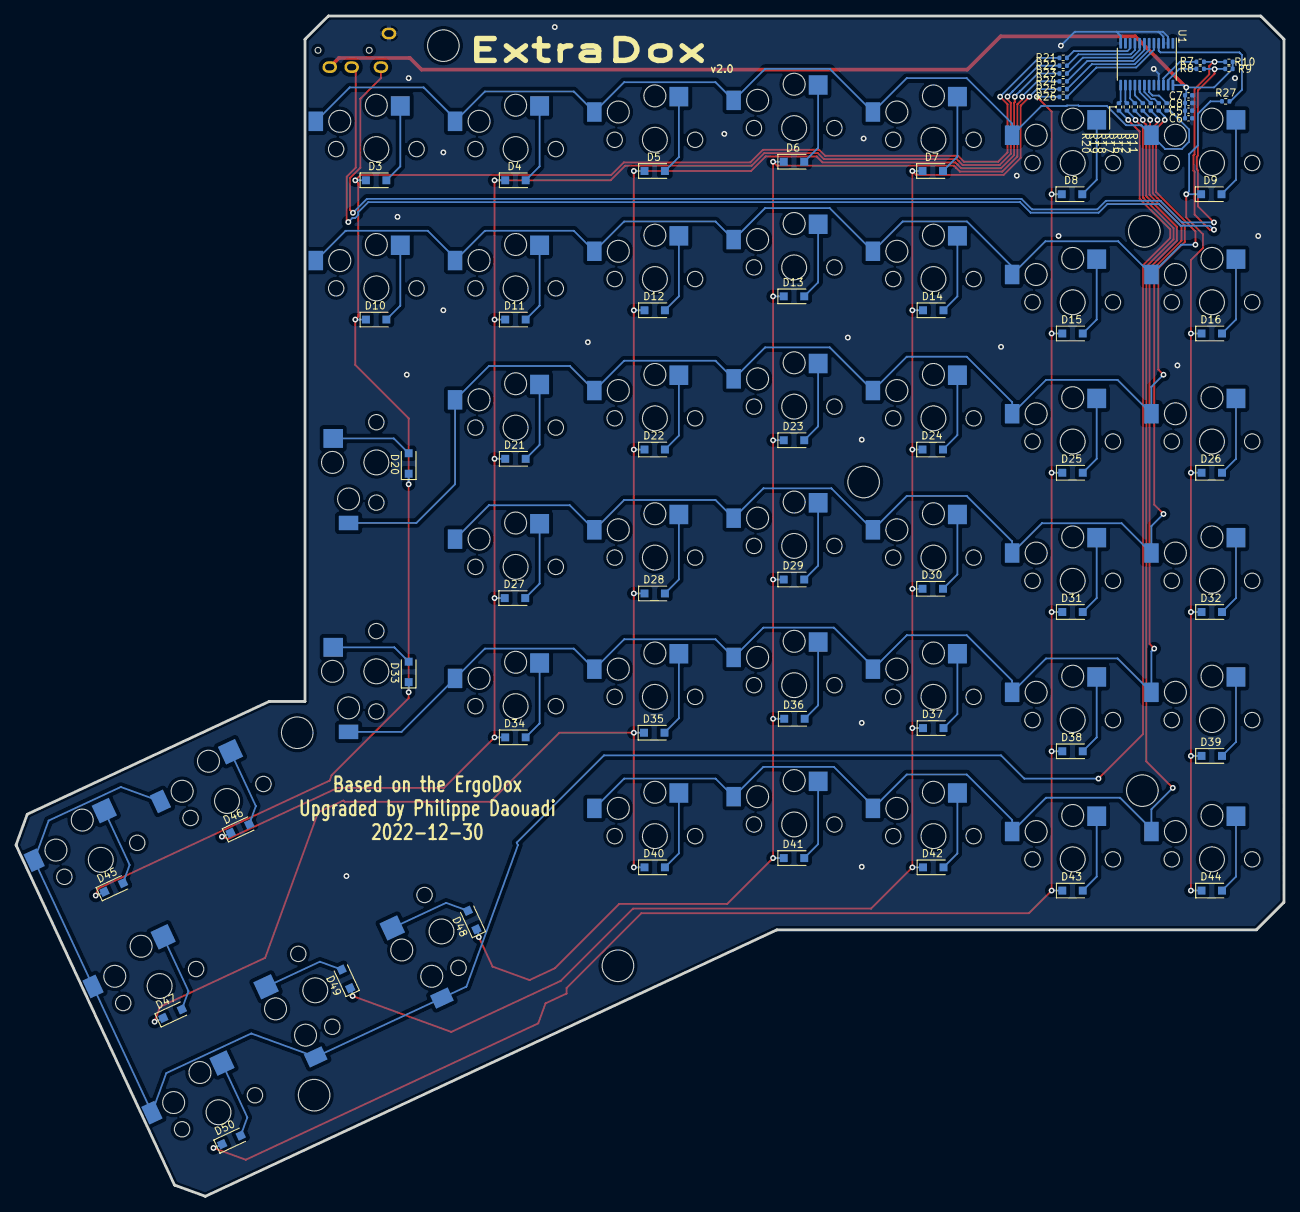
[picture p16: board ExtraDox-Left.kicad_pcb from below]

Board: 2 copper layers, 173.4 x 161.4 mm, 114 parts (68 on the bottom side), 79 nets.

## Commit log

2023-05-13 README: add note about buying boards
2024-11-03 README: no more boards to sell
